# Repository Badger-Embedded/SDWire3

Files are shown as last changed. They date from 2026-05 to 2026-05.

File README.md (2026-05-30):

# SDWire3 Flex

## This project is the fork of [SD Swap](https://github.com/Mr-Bossman/SD_Swap) project. The development tool which swaps an SD card between a USB3 card reader and a DUT.

### About

SDWire3 allows reflashing of an SD card connected to the DUT (Device Under Test), without physical contact with the device. The board is designed in such way that it fits into micro SD card slots. Thanks to this, there is no need for special cables with a micro SD adapter, though it may be beneficial to add an extention to avoid accidentally breaking your boards SD connector if someone yanks the cable.

Design is changed to have flex cable instead of solid pcb as dummy sdcard which will be connected to DUT.

**IMPORTANT**

Faster SD cards may not work on some single board computers as the
timing and capacitance on the SBC side is not right.

### Rational

After seeing the [SDWire](https://wiki.tizen.org/SDWire) project I was disappointed by the complexity as well as the lack of USB3. So this project is uses the REALTEK RTS5306E controller which many USB3 to SD adapters use. The chip has power suspend functionality which we can use as a GPIO for switching hosts. The suspend option will shut off the SD cards power but not the controllers; it also has build-in RW protection as to finish writes before switching to the SBC

The SDWire project uses a USB to GPIO chip for this, but they have two power controlled USB ports on the board as well as the above mentioned method.

### Software

To swap the SD card between the host PC and the SBC you run
`sdswap 0` or `sdswap 1`.

`1` is the host PC while `0` is the SBC. You can also chose which device to use if you have multiple attached. To do this run `sdswap 1` to print the found devices and type `sdswap 1-4 1` or another USB number. I have future plans to write this script for Windows and OSX.

```
$ sdswap -h

To switch the SD card to USB run:
sdswap 1
To switch the SD card to SBC run:
sdswap 0
To print the block dev run:
sdswap p

If you have multiple devices run either of the above.
Then run with the last param the same as above:
sdswap $(Your USB number) 0

NOTE:
When printing the block device the script waits until the device exists

Examples:
# sdswap 0
Uisng device /sys/bus/usb/devices/3-4

# sdswap 0
Uisng device /sys/bus/usb/devices/3-4
Already off.

# sdswap p
/dev/sda

# sdswap 0
Multiple devices found! Pass a usb number as param 1...
Usb num: 3-4
Usb num: 3-1

# sdswap 3-1 0
Uisng device /sys/bus/usb/devices/3-1
```

To manually controll the port use:

```
export YOUR_USB_NUM="1-4" #hub1 port4
echo 0 | sudo tee /sys/bus/usb/devices/${YOUR_USB_NUM}/power/autosuspend_delay_ms
echo auto | sudo tee /sys/bus/usb/devices/${YOUR_USB_NUM}/power/control

echo SBC
echo ${YOUR_USB_NUM} | sudo tee /sys/bus/usb/drivers/usb/unbind

echo PC
echo ${YOUR_USB_NUM} | sudo tee /sys/bus/usb/drivers/usb/bind
```

### Hardware

#### LEDs

- D2 is the **red/blue** status LED it will be **blue** when the in passthrough mode, and **red** when the USB3 controller is reading/writing to it.
- D1 is the **yellow** activity LED and blinks when the USB3 controller is reading/writing.
- D3 is the **red** power LED and is active when the USB3 controller has power.

**NOTE**: The **red** power LED will not be on if the USB cable isn't 5V providing power.

### TODO

- Fix SBC side timeing
- Write script for Windows and OSX.
- Edit pick n' place csv
- Label stat leds
- Add use switching regulator
- Add E-Fuse
- Update readme

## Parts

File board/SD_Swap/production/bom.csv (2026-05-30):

Designator | Footprint | Quantity | Value | LCSC Part #
C1, C18, C22, C3 | 0402 | 4 | 4u7 | C23733
C11, C14, C16, C20 | 0402 | 4 | 1u | C107372
C12, C17, C2, C23, C25, C28, C4, C5, C6, C7, C8 | 0201 | 11 | 100n | C66938
C15, C24, C9 | 0201 | 3 | 2u2 | C76933
C19 | 0603 | 1 | 10u | C19702
C26, C27 | 0201 | 2 | 30p | C384980
D1 | 0402 | 1 | LED | C71911
D2 | SOT-323_SC-70 | 1 | BAT54CW | C57891
D3 | LED_RGB_1210 | 1 | PROG/PASS | C264332
J1 | USB_C_Receptacle_Amphenol_10137061-00021LF | 1 | USB_C | C3197967
L1 | 0402 | 1 | 2u2 | C383389
Q1 | SOT-23-6 | 1 | Q_Dual_PNP_PNP_E1B1C2E2B2C1 | C111730
R1, R3 | 0402 | 2 | 6.2K LED | C25915
R10, R6, R7, R9 | 0201 | 4 | 6.2K | C295814
R2 | 0201 | 1 | 5.1K | C100142
R4, R5 | 0201 | 2 | 100 | C2991668
R8 | 0201 | 1 | 680R | C473509
U1 | SOT-363_SC-70-6 | 1 | 74LVC2G14 | C3294721
U2 | QFN-64-1EP_8x8mm_P0.4mm_EP6.5x6.5mm_ThermalVias | 1 | GL3231S | C7435977
U3 | WQFN-24-1EP_4x4mm_P0.5mm_EP2.6x2.6mm | 1 | TS3A27518ERTW | C2651937
U4 | 105162-0001 | 1 | SD_SOCKET(DUT) | C724031
U5 | 105162-0001 | 1 | SD_SOCKET | C724031
U6 | SOIC-8_3.9x4.9mm_P1.27mm | 1 | W25X10CLSNIG | C164120
Y1 | Crystal_SMD_2520-4Pin_2.5x2.0mm | 1 | 25MHz 18pF | C255956

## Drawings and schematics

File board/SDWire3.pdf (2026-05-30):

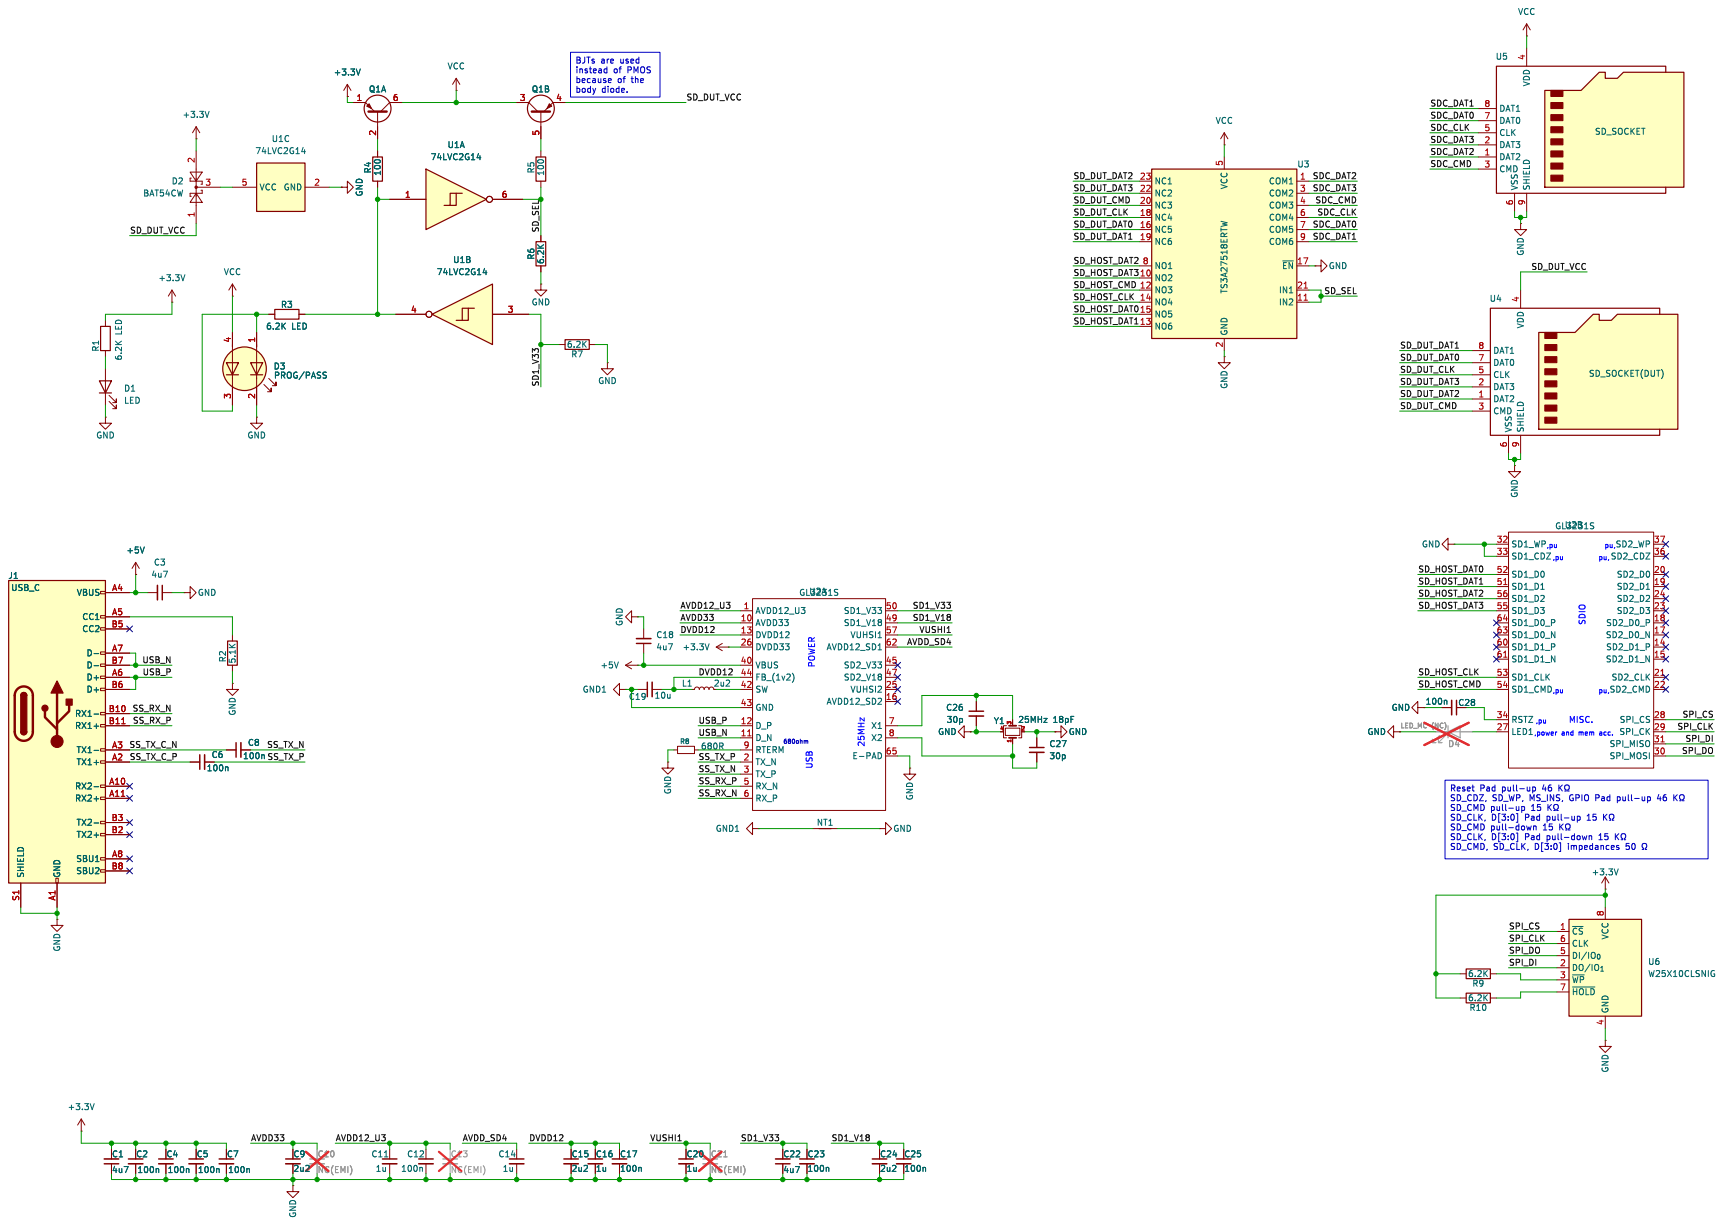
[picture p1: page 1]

,power and mem acc. MISC.SDIO

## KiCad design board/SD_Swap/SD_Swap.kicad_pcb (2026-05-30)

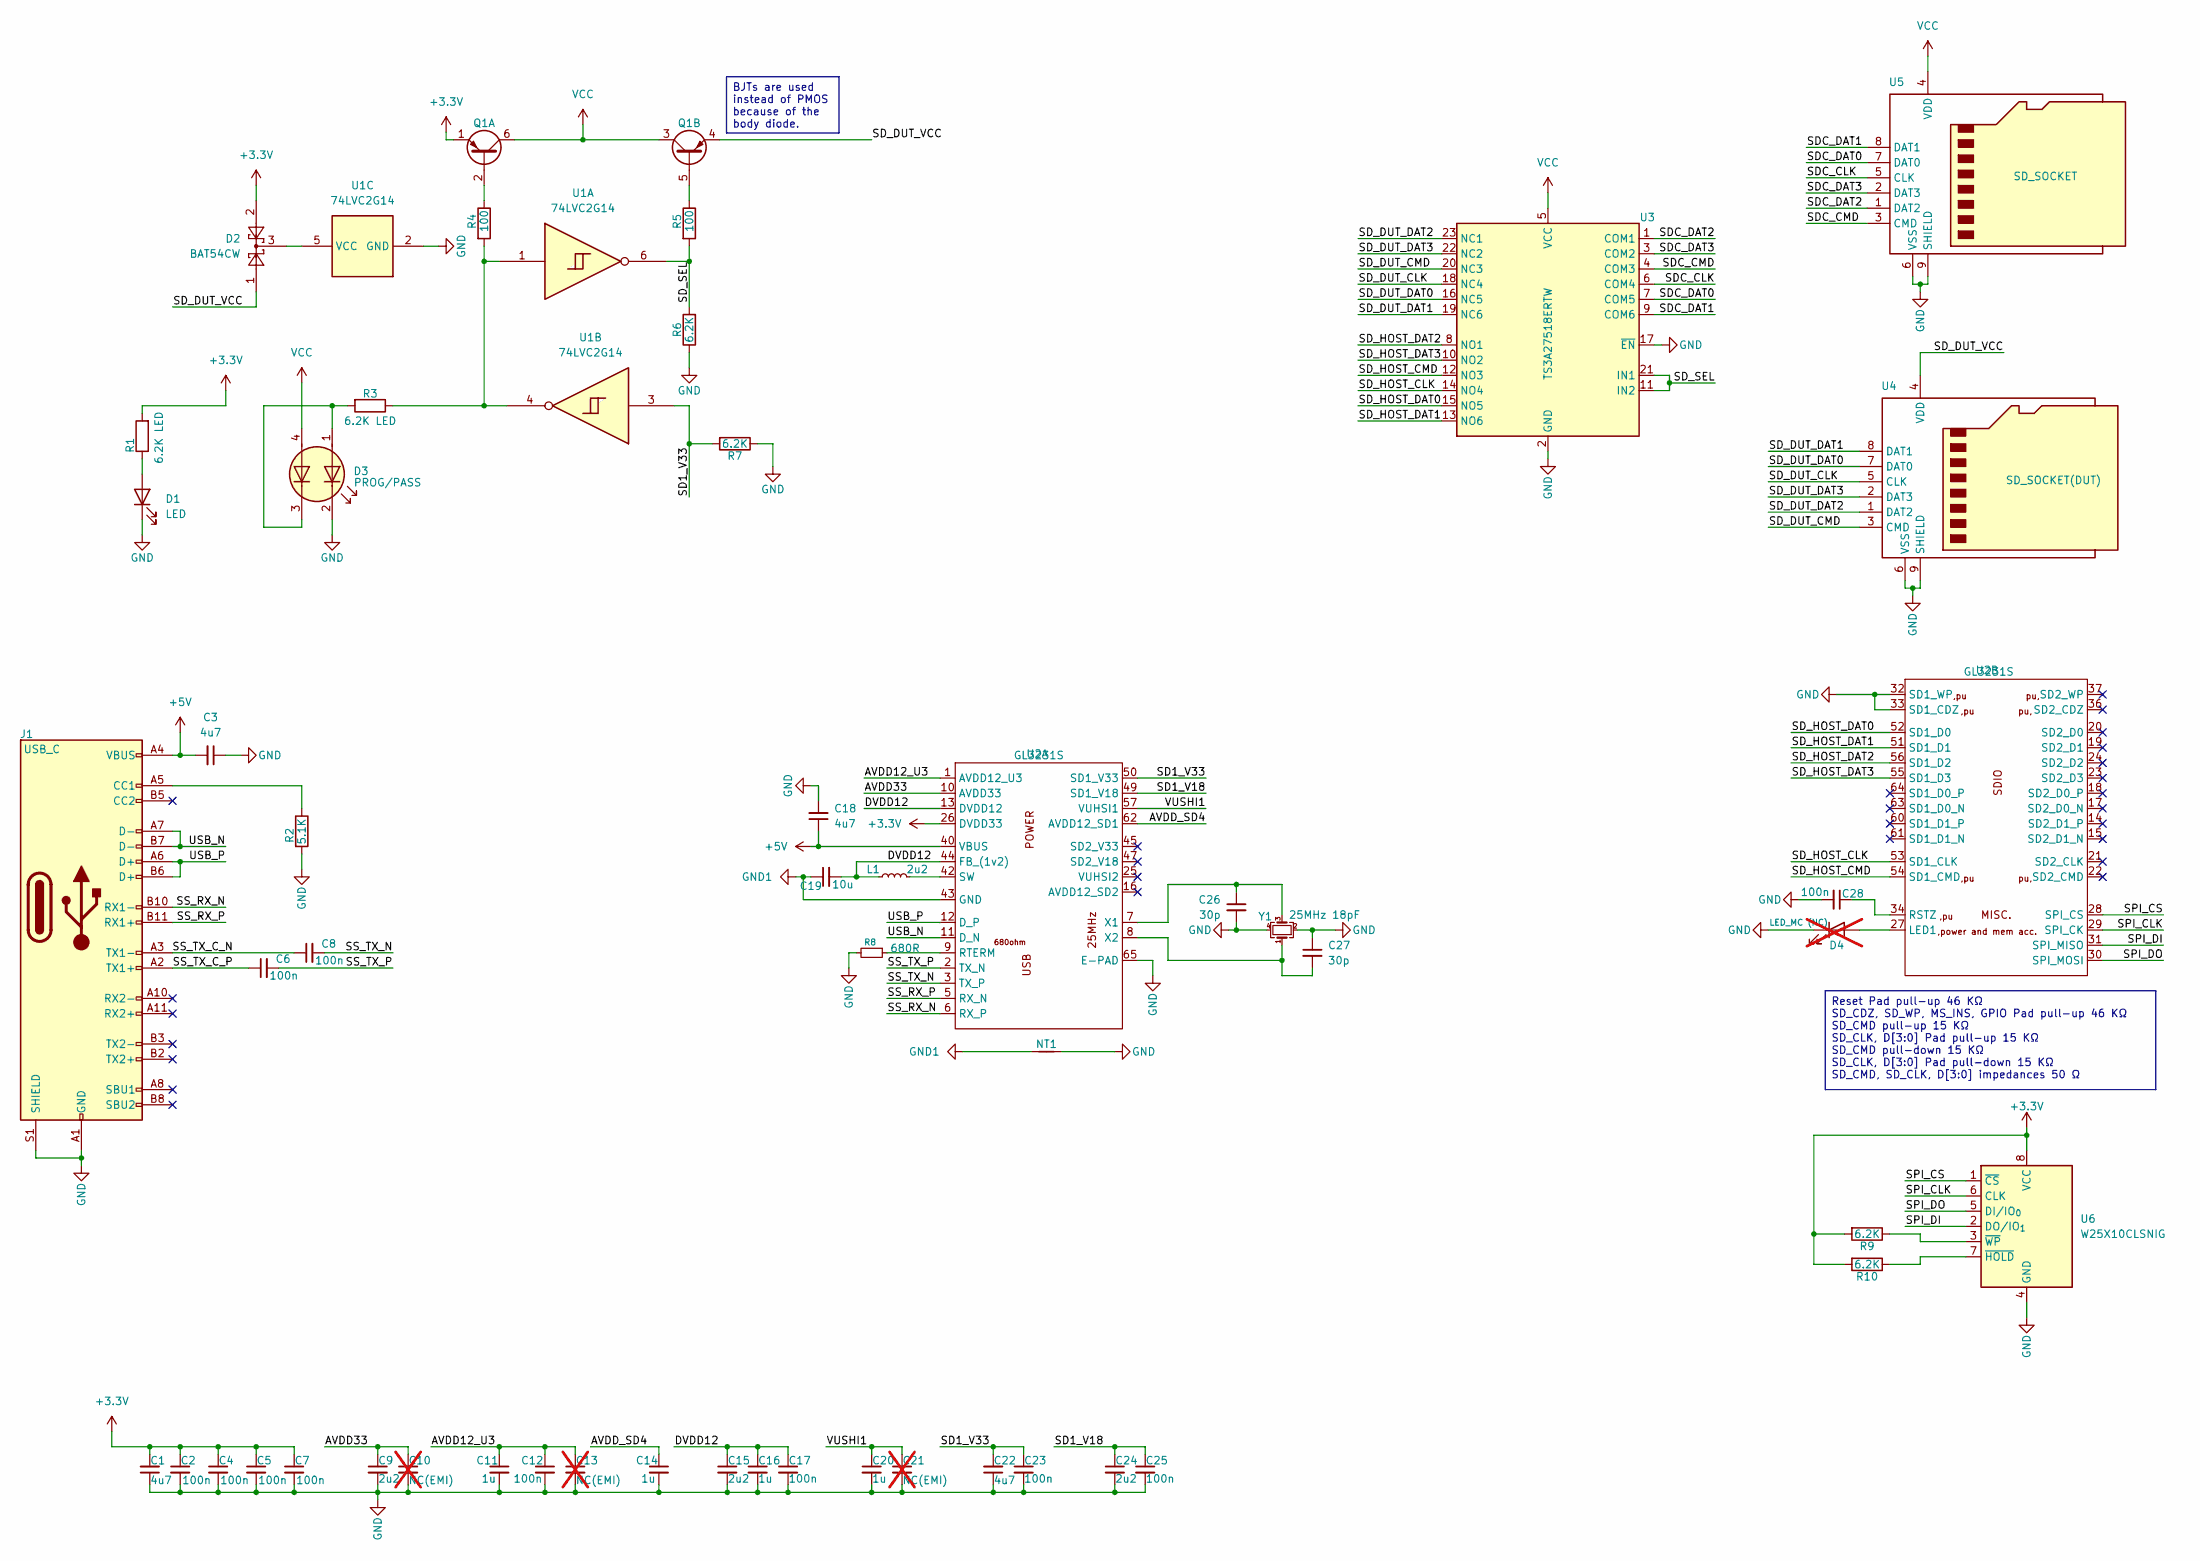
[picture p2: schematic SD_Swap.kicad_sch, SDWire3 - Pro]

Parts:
C1, C3, C18, C22: 4u7; C_0402_1005Metric; LCSC C23733
C2, C4, C5, C6, C7, C8, C12, C17, C23, C25, C28: 100n; C_0201_0603Metric; LCSC C66938
C9, C15, C24: 2u2; C_0201_0603Metric; LCSC C76933
C10, C13, C21: NC(EMI); C_0201_0603Metric; not fitted
C11, C14, C16, C20: 1u; C_0402_1005Metric; LCSC C107372
C19: 10u; C_0603_1608Metric; LCSC C19702
C26, C27: 30p; C_0201_0603Metric; LCSC C384980
D1: LED; LED_0402_1005Metric; LCSC C71911
D2: BAT54CW; SOT-323_SC-70; LCSC C57891
D3: PROG/PASS; LED_RGB_1210; LCSC C264332
D4: LED_MC (NC); LED_0603_1608Metric; not fitted
J1: USB_C; USB_C_Receptacle_Amphenol_10137061-00021LF; Part Number 10137061-00021LF; LCSC C3197967
L1: 2u2; L_0402_1005Metric; LCSC C383389
NT1: NetTie_2; NetTie-2_SMD_Pad0.5mm
Q1: Q_Dual_PNP_PNP_E1B1C2E2B2C1; SOT-23-6; LCSC C111730
R1, R3: 6.2K LED; R_0402_1005Metric; LCSC C25915
R2: 5.1K; R_0201_0603Metric; LCSC C100142
R4, R5: 100; R_0201_0603Metric; LCSC C2991668
R6, R7, R9, R10: 6.2K; R_0201_0603Metric; LCSC C180341
R8: 680R; R_0201_0603Metric; LCSC C473509
U1: 74LVC2G14; SOT-363_SC-70-6; LCSC C3294721
U2: GL3231S; QFN-64-1EP_8x8mm_P0.4mm_EP6.5x6.5mm_ThermalVias; LCSC C7435977
U3: TS3A27518ERTW; WQFN-24-1EP_4x4mm_P0.5mm_EP2.6x2.6mm; Part Number TS3A27518ERTW; LCSC C2651937
U4: SD_SOCKET(DUT); 105162-0001; Part Number 105162-0001; LCSC C724031
U5: SD_SOCKET; 105162-0001; Part Number 105162-0001; LCSC C724031
U6: W25X10CLSNIG; SOIC-8_3.9x4.9mm_P1.27mm; LCSC C164120
Y1: 25MHz 18pF; Crystal_SMD_2520-4Pin_2.5x2.0mm; LCSC C255956

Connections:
+3.3V: C1.2, C2.1, C4.1, C5.1, C7.1, D2.2, Q1.1 (E1), R1.2, R9.2, R10.2, U2.26 (DVDD33), U2.39 (DVDD33), U2.46 (DVDD33), U2.48 (DVDD33), U2.58 (DVDD33), U6.8 (VCC)
+5V: C3.2, C18.1, J1.A4 (VBUS), J1.A9 (VBUS), J1.B4 (VBUS), J1.B9 (VBUS), U2.40 (VBUS), U2.41 (VBUS)
/AVDD12_U3: C11.1, C12.1, C13.1, U2.1 (AVDD12_U3), U2.4 (AVDD12_U3)
/AVDD33: C9.1, C10.1, U2.10 (AVDD33)
/AVDD_SD4: C14.1, U2.62 (AVDD12_SD1)
/DVDD12: C15.1, C16.1, C17.1, C19.2, L1.1, U2.13 (DVDD12), U2.38 (DVDD12), U2.44 (FB_(1v2)), U2.59 (DVDD12)
/SD1_V18: C24.1, C25.1, U2.49 (SD1_V18)
/SD1_V33: C22.2, C23.1, R7.2, U1.3, U2.50 (SD1_V33)
/SDC_CLK: U3.6 (COM4), U5.5 (CLK)
/SDC_CMD: U3.4 (COM3), U5.3 (CMD)
/SDC_DAT0: U3.7 (COM5), U5.7 (DAT0)
/SDC_DAT1: U3.9 (COM6), U5.8 (DAT1)
/SDC_DAT2: U3.1 (COM1), U5.1 (DAT2)
/SDC_DAT3: U3.3 (COM2), U5.2 (DAT3)
/SD_DUT_CLK: U3.18 (NC4), U4.5 (CLK)
/SD_DUT_CMD: U3.20 (NC3), U4.3 (CMD)
/SD_DUT_DAT0: U3.16 (NC5), U4.7 (DAT0)
/SD_DUT_DAT1: U3.19 (NC6), U4.8 (DAT1)
/SD_DUT_DAT2: U3.23 (NC1), U4.1 (DAT2)
/SD_DUT_DAT3: U3.22 (NC2), U4.2 (DAT3)
/SD_DUT_VCC: D2.1, Q1.4 (E2), U4.4 (VDD)
/SD_HOST_CLK: U2.53 (SD1_CLK), U3.14 (NO4)
/SD_HOST_CMD: U2.54 (SD1_CMD), U3.12 (NO3)
/SD_HOST_DAT0: U2.52 (SD1_D0), U3.15 (NO5)
/SD_HOST_DAT1: U2.51 (SD1_D1), U3.13 (NO6)
/SD_HOST_DAT2: U2.56 (SD1_D2), U3.8 (NO1)
/SD_HOST_DAT3: U2.55 (SD1_D3), U3.10 (NO2)
/SD_SEL: R5.2, R6.2, U1.6, U3.11 (IN2), U3.21 (IN1)
/SPI_CLK: U2.29 (SPI_CK), U6.6 (CLK)
/SPI_CS: U2.28 (SPI_CS), U6.1 (~CS)
/SPI_DI: U2.31 (SPI_MISO), U6.2 (DO/IO_{1})
/SPI_DO: U2.30 (SPI_MOSI), U6.5 (DI/IO_{0})
/SS_RX_N: J1.B10 (RX1-), U2.6 (RX_P)
/SS_RX_P: J1.B11 (RX1+), U2.5 (RX_N)
/SS_TX_C_N: C8.1, J1.A3 (TX1-)
/SS_TX_C_P: C6.1, J1.A2 (TX1+)
/SS_TX_N: C8.2, U2.3 (TX_P)
/SS_TX_P: C6.2, U2.2 (TX_N)
/USB_N: J1.A7 (D-), J1.B7 (D-), U2.11 (D_N)
/USB_P: J1.A6 (D+), J1.B6 (D+), U2.12 (D_P)
/VUSHI1: C20.1, C21.1, U2.57 (VUHSI1)
GND: C1.1, C2.2, C3.1, C4.2, C5.2, C7.2, C9.2, C10.2, C11.2, C12.2, C13.2, C14.2, C15.2, C16.2, C17.2, C18.2, C20.2, C21.2, C22.1, C23.2, C24.2, C25.2, C26.2, C27.1, C28.2, D1.1 (K), D3.2 (K1), D4.1 (K), J1.A1 (GND), J1.A12 (GND), J1.B1 (GND), J1.B12 (GND), J1.S1 (SHIELD), NT1.2, R2.2, R6.1, R7.1, R8.2, U1.2 (GND), U2.32 (SD1_WP), U2.33 (SD1_CDZ), U2.65 (E-PAD), U3.2 (GND), U3.17 (~EN), U3.25 (GND), U4.6 (VSS), U4.9 (SHIELD), U4.10 (SHIELD), U4.11 (SHIELD), U4.12 (SHIELD), U4.13 (SHIELD), U4.14 (SHIELD), U4.15 (SHIELD), U5.6 (VSS), U5.9 (SHIELD), U5.10 (SHIELD), U5.11 (SHIELD), U5.12 (SHIELD), U5.13 (SHIELD), U5.14 (SHIELD), U5.15 (SHIELD), U6.4 (GND), Y1.2, Y1.4
GND1: C19.1, NT1.1, U2.43 (GND)
unnamed: D1.2 (A), R1.1
unnamed: D3.1 (A1), D3.3 (K2), R3.2
unnamed: D4.2 (A), U2.27 (LED1)
unnamed: J1.A5 (CC1), R2.1
unnamed: Q1.2 (B1), R4.1
unnamed: Q1.5 (B2), R5.1
unnamed: R3.1, R4.2, U1.1, U1.4
unnamed: D2.3, U1.5 (VCC)
unnamed: R8.1, U2.9 (RTERM)
unnamed: L1.2, U2.42 (SW)
unnamed: C26.1, U2.7 (X1), Y1.3
unnamed: C27.2, U2.8 (X2), Y1.1
unnamed: C28.1, U2.34 (RSTZ)
unnamed: R10.1, U6.7 (~HOLD)
unnamed: R9.1, U6.3 (~WP)
VCC: D3.4 (A2), Q1.3 (C2), Q1.6 (C1), U3.5 (VCC), U5.4 (VDD)

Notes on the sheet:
BJTs are used instead of PMOS because of the body diode.
Reset Pad pull-up 46 KΩ SD_CDZ, SD_WP, MS_INS, GPIO Pad pull-up 46 KΩ SD_CMD pull-up 15 KΩ SD_CLK, D[3:0] Pad pull-up 15 KΩ SD_CMD pull-down 15 KΩ SD_CLK, D[3:0] Pad pull-down 15 KΩ SD_CMD, SD_CLK, D[3:0] impedances 50 Ω

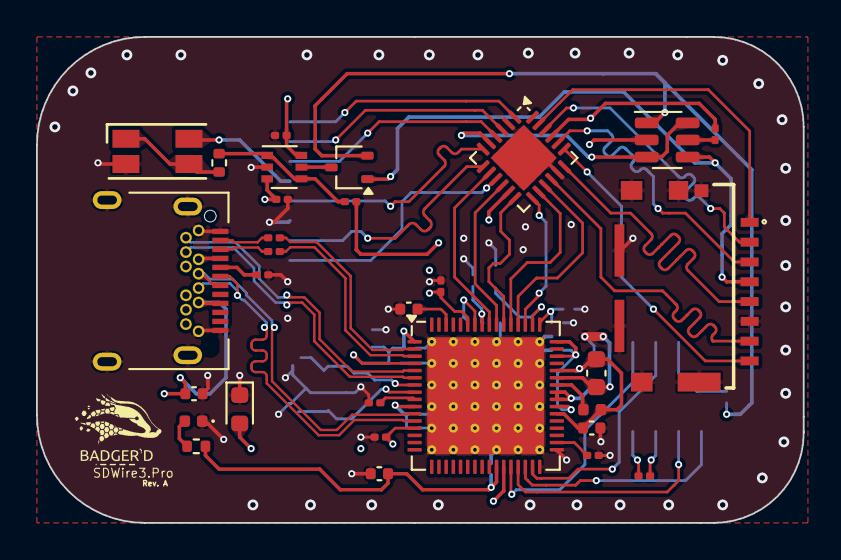
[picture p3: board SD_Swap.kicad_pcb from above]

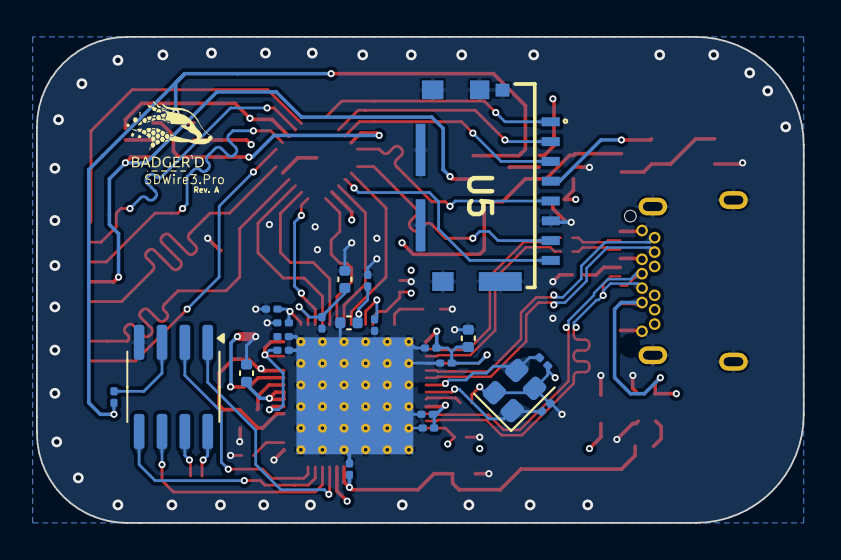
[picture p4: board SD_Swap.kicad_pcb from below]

Board: 4 copper layers, 42.6 x 27.0 mm, 53 parts (22 on the bottom side), 59 nets.
